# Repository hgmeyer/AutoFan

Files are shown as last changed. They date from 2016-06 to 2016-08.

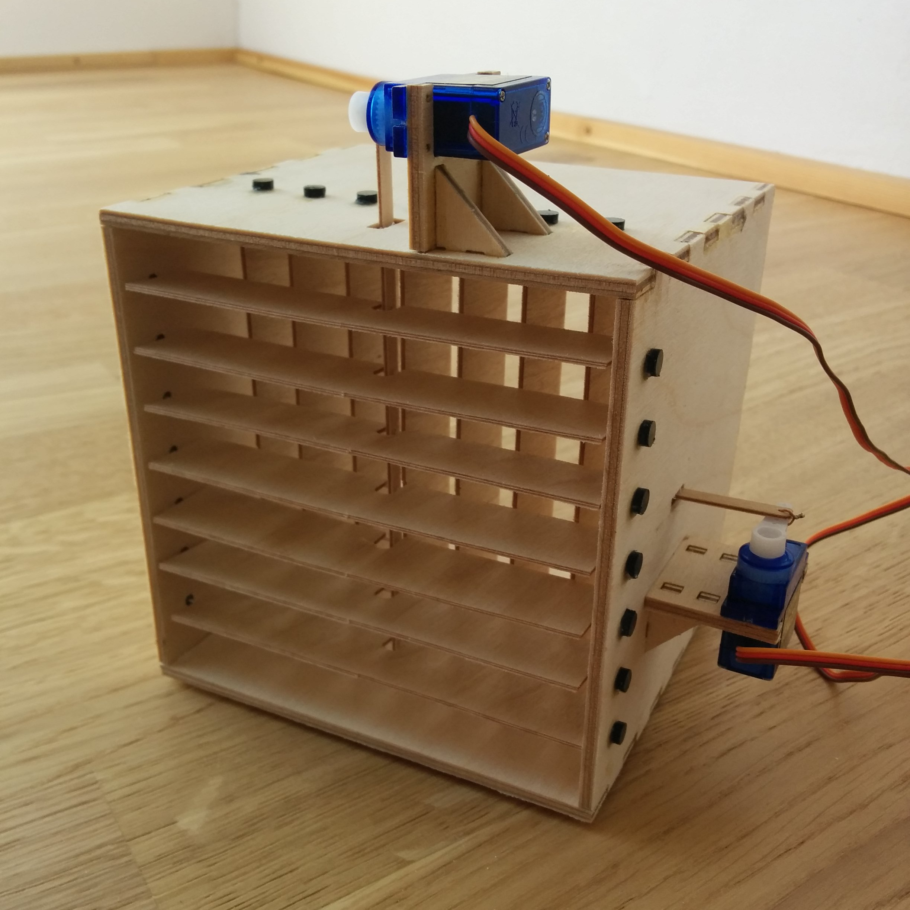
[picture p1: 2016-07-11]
images/front_assembled.jpg

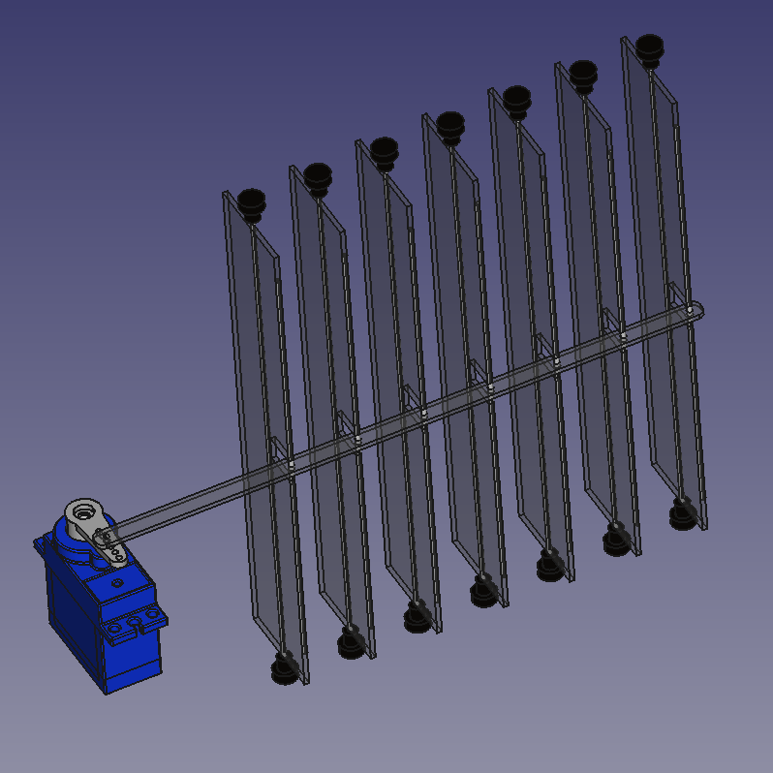
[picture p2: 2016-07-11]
images/lamellae_mechanics.png

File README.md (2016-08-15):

# AutoFan


AutoFan is a prototype for controlling the direction of air flow of a fan based on computer vision in order to avoid fatigue during long distance car drives. It uses a *low-cost camera* (e.g. a webcam), a *Raspberry Pi 2*, a *face recognition algorithm*, an algorithm for *eye blink detection* and two *servo motors* controlling the lamellae of a *custom-made fan*. By inferring the position of a face from the camera images the servo motor angles are adjusted to point the airflow into (or away) from the face. By measuring eye blink frequency the system automatically points the air flow into the direction of the driver's face if the driver has been detected to be tired.

**Please note:** This is the repository for a project hosted on [hackaday.io](http://hackaday.io/). Please visit the [project page](https://hackaday.io/project/12384-autofan-automated-air-flow-direction-control) for more information.

<br />This work is licensed under a <a rel="license" href="http://creativecommons.org/licenses/by-sa/4.0/">Creative Commons Attribution-ShareAlike 4.0 International License</a>.

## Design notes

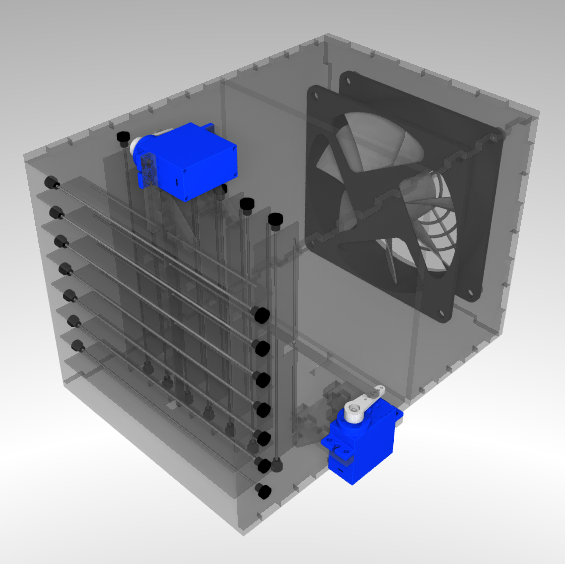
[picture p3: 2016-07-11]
cad/renderings/autofan_render_transparent.png

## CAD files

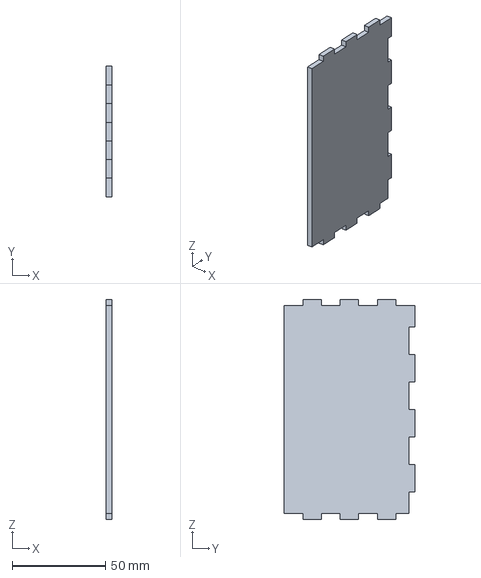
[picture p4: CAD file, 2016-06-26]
cad/iges/back_right.iges
3.00 x 70.0 x 118.0 mm

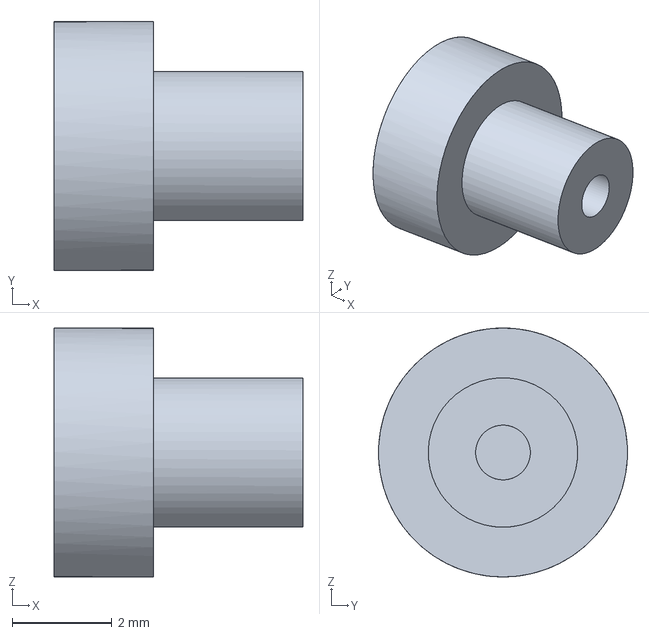
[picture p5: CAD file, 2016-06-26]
cad/iges/bearing.iges
5.00 x 5.00 x 5.00 mm

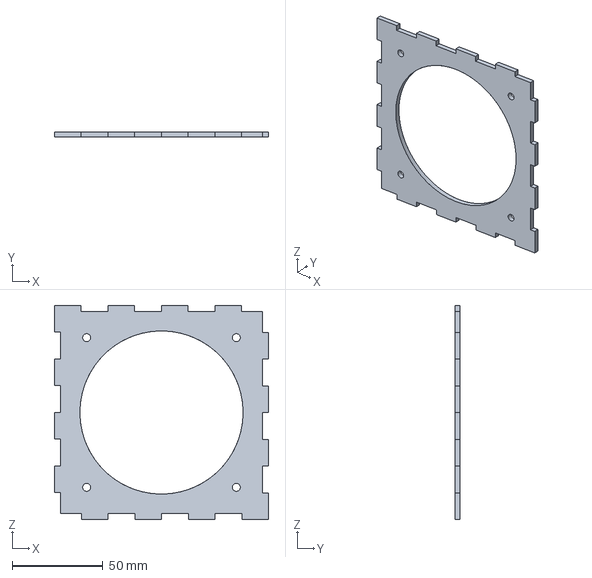
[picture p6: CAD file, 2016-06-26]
cad/iges/back_back.iges
118.0 x 3.00 x 118.0 mm

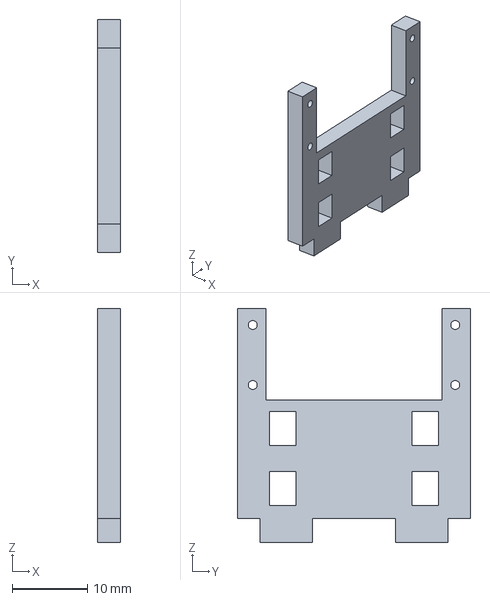
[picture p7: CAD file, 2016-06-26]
cad/iges/servo_holder_plate.iges
3.00 x 31.0 x 31.2 mm

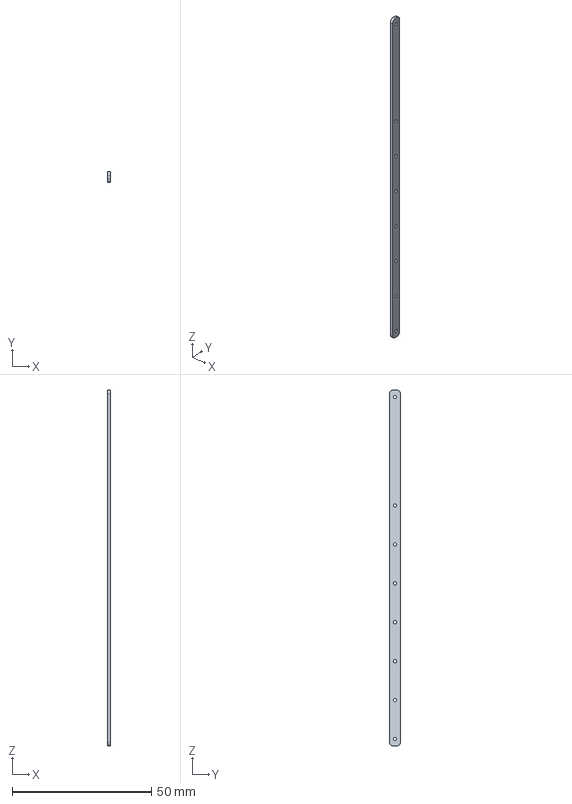
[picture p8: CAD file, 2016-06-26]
cad/iges/servo_horn.iges
1.00 x 4.00 x 128.0 mm

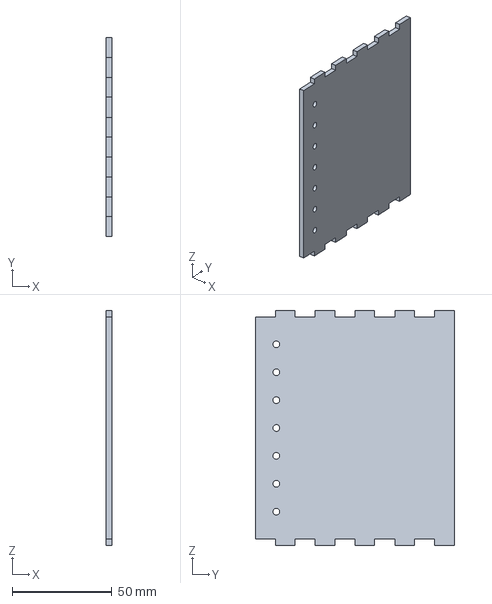
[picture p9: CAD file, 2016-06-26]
cad/iges/front_left.iges
3.00 x 100.0 x 118.0 mm

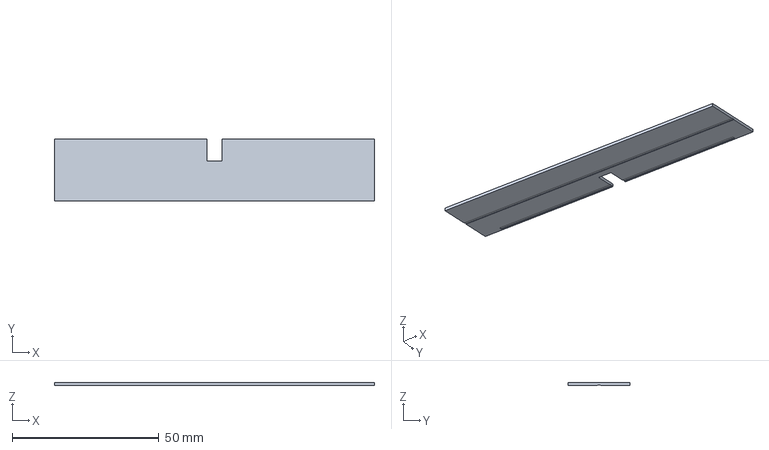
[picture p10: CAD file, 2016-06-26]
cad/iges/lamella.iges
109.0 x 21.0 x 1.00 mm

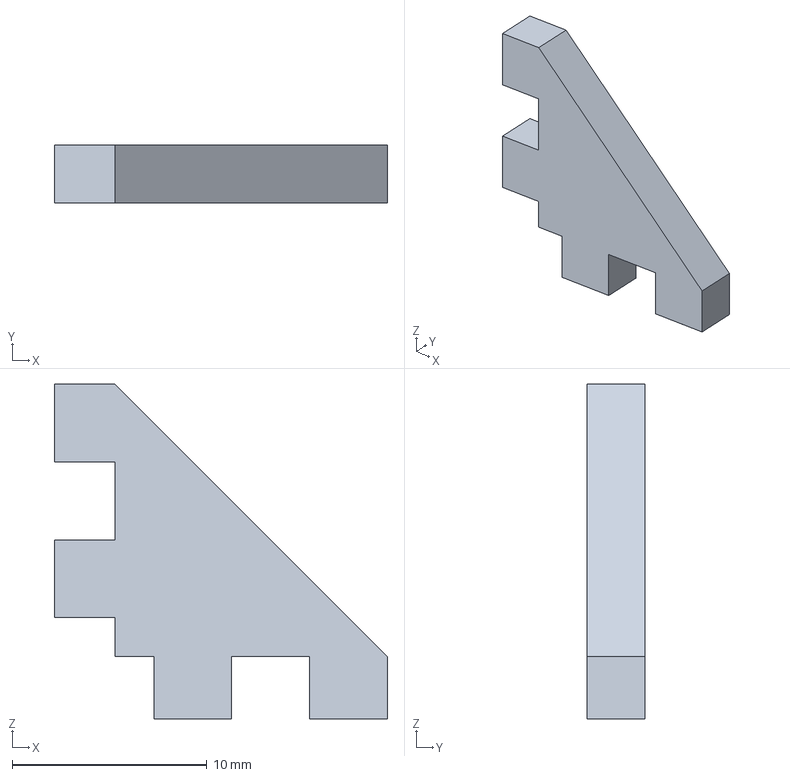
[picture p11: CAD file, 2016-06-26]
cad/iges/servo_holder_leg.iges
17.1 x 3.00 x 17.2 mm

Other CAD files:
cad/iges/back_top.iges
cad/iges/back_left.iges
cad/iges/back_bottom.iges
cad/iges/front_right.iges
cad/iges/front_bottom.iges
cad/iges/front_top.iges

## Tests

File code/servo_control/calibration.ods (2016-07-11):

 | Servo horizontal (1) | Servo vertical (3)
PWM | angle | angle
100 | -51 | 49
110 | -45 | 46
120 | -38 | 38
130 | -30 | 30
140 | -23 | 22
150 | -15 | 15
160 | -6 | 6
170 | 2 | -2
180 | 11 | -7
190 | 18 | -20
200 | 29 | -28
210 | 36 | -35
220 | 45 | -44
230 |  | -50
m= | 1,2290352706 | -1,2517764093
b= | 166,3342587025 | 166,7882520133
slip | 0 | 0

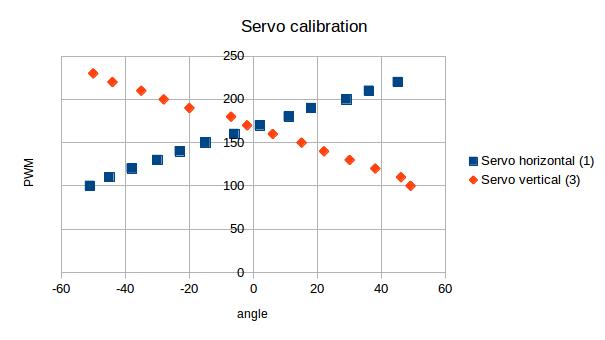
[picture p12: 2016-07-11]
images/servo_calibration.jpg

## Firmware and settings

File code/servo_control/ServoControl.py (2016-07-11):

import math
import multiprocessing
import time
import copy
import sharedmem

from Filter import lowpass


class ServoControl(multiprocessing.Process):
    def __init__(self, servo_horizontal, m_horizontal, b_horizontal,
                 servo_vertical, m_vertical, b_vertical,
                 f, speed, pwm_min, pwm_max):

        # Initialize multiprocessing.Process parent
        multiprocessing.Process.__init__(self)

        # Exit event for stopping process
        self._exit = multiprocessing.Event()

        # Set servo pins
        self._s_h = servo_horizontal
        self._s_v = servo_vertical

        # Set slopes
        self._m_horizontal = m_horizontal
        self._m_vertical = m_vertical

        # Set intercepts
        self._b_horizontal = b_horizontal
        self._b_vertical = b_vertical

        # Set update frequency
        self._f = 1.0 / f

        # Set increment per time step
        self._increment = speed / f

        # Set minimum and maximum pwm ranges
        self._pwm_min = pwm_min
        self._pwm_max = pwm_max

        # An array in shared memory for storing the new desired servo position angles
        self._newangles = sharedmem.zeros((2, 1), dtype='float')

        # A list containing the current servo angles
        self._currentangles = sharedmem.ones((2, 1), dtype='float')

        # Initialize ServoBlaster device
        self._servoblaster = open('/dev/servoblaster', 'w')

    def __del__(self):
        self._servoblaster.close()

    def run(self):
        # Clear events
        self._exit.clear()

        self._set_servo_pwm(self._s_h, self._currentangles[0])
        self._set_servo_pwm(self._s_v, self._currentangles[1])

        old_horizontal_angle = self._currentangles[0]
        old_vertical_angle = self._currentangles[1]

        # While exit event is not set...
        while not self._exit.is_set():

            # ...increment or decrement horizontal servo angle depending on speed and update frequency
            if self._newangles[0] > self._currentangles[0]:
                self._currentangles[0] += self._increment
            elif self._newangles[0] < self._currentangles[0]:
                self._currentangles[0] -= self._increment

            # ...increment or decrement vertical servo angle depending on speed and update frequency
            if self._newangles[1] > self._currentangles[1]:
                self._currentangles[1] += self._increment
            elif self._newangles[1] < self._currentangles[1]:
                self._currentangles[1] -= self._increment

            # ...apply temporal lowpass filter to angles
            new_horizontal_angle = lowpass(self._currentangles[0],
                                           old_horizontal_angle,
                                           0.1, self._f)

            new_vertical_angle = lowpass(self._currentangles[0],
                                         old_vertical_angle,
                                         0.1, self._f)

            # ...store angles
            old_horizontal_angle = new_horizontal_angle
            old_vertical_angle = new_vertical_angle

            # ...set servo pwm
            self._set_servo_pwm(self._s_h, self.angle_to_pwm(new_horizontal_angle,
                                                             self._m_horizontal, self._b_horizontal))
            self._set_servo_pwm(self._s_v, self.angle_to_pwm(new_vertical_angle,
                                                             self._m_vertical, self._b_vertical))

            time.sleep(self._f)

    def set_new_angles(self, horizontal_angle, vertical_angle):
        self._newangles[0] = copy.copy(horizontal_angle)
        self._newangles[1] = copy.copy(vertical_angle)

    def _set_servo_pwm(self, servo, pwm):
        if pwm in range(self._pwm_min, self._pwm_max, 1):
            self._servoblaster.write(str(servo) + '=' + str(pwm) + '\n')
            self._servoblaster.flush()

    def angle_to_pwm(self, angle, m, b):
        if math.isnan(angle):
            return self._pwm_min
        else:
            pwm = m * angle + b
            return int(pwm)


if __name__ == '__main__':
    servocontrol = ServoControl(1, 1.2290352706, 166.3342587025,
                                3, -1.2517764093, 166.7882520133,
                                100, 100, 90, 226)
    servocontrol.start()

    while True:
        servocontrol.set_new_angles(30, 30)
        time.sleep(1)
        servocontrol.set_new_angles(-30, -30)
        time.sleep(1)

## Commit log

2016-06-24 Added CAD files for the mechanical prototype.
2016-06-24 Added rendering of mechanical prototype
2016-06-26 Added IGES files for mechanical prototype
    [back_back.iges, back_bottom.iges, back_left.iges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]
2016-06-26 Added image of assembled prototype
2016-06-27 Fixed fan orientation (thanks, helge!)
2016-06-27 Updated rendering to account for fan orientation change
2016-07-11 Added image of assembled mechanics
2016-07-11 Added servo_control thread
    [calibration.ods]
2016-07-11 Switched from using method access to copy method from copy module
2016-07-11 Added servo calibration image
2016-07-13 Added class for unwarping camera images
